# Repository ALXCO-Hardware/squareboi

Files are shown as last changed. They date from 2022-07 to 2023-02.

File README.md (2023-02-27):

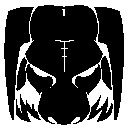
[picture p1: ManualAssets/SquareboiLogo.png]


# Squareboi

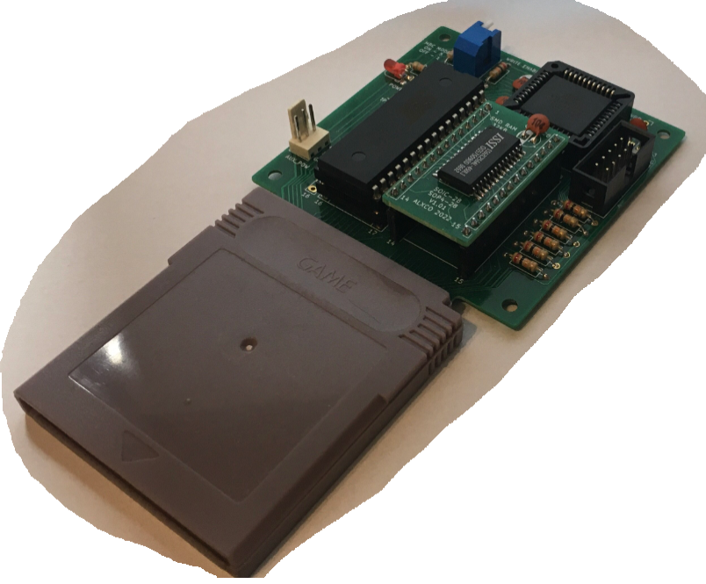
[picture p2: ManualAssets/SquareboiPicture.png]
Squareboi


Squareboi is an open hardware cartridge system for the Game Boy Color, made to be as accessible and DIY-friendly as possible.
Using a handful of off-the-shelf components, it provides the same functionality as an original cartridge, compatible with the majority of programs.
Additionally, an Arduino-based programmer allows for easy transfer of games and save data.

## Features

Up to 4MB ROM/32KB RAM storage space

Stores save data without needing a battery

Made of common, off-the-shelf parts

Fully compatible with MBC1 and MBC5 mappers, partial support for MBC2 and MBC3

Programmer works as a general purpose cartridge reader

Easy to build: A basic version can be made with entirely through-hole components

Powered by a single 5V rail

Compatible with third-party programmers, like the widespread GBxCart RW

## Manual

A thorough explanation of how the system works, and how to assemble it, can be found in the manual file, [HERE.](/Manual.pdf)

## Acknowledgements

Squareboi's existence is only possible due to the continued efforts of multiple individuals dedicated to reverse engineering and documenting the Game Boy hardware.
A full list of those whose work I've built upon can be found within the manual.

Still, I'd like to say it again: Thanks to all of you! I wouldn't have gotten here alone.

## Links

[Official video assembly guide](https://www.youtube.com/playlist?list=PL5rO9JlAGJ3c4BWqF0iWA5yTH4LZhnxgb)

[Squareboi featured on Hackaday](https://hackaday.com/2022/08/16/squareboi-is-the-diy-game-boy-cart-youve-always-wanted/)

## License

Squareboi is the work of a hobbyist – And while significant care was 
taken to make it reliable, I cannot guarantee that it will work in 
your specific use case, or that it will be compatible with your 
hardware.

Squareboi is licensed under the Creative Commons Attribution 4.0 
International License (CC BY 4.0). 
https://creativecommons.org/licenses/by/4.0/#deed-conditions

In essence, if you share or adapt this work, you must credit the 
author (ALXCO), and provide a link to the Squareboi repository, at:
https://github.com/ALXCO-Hardware/squareboi

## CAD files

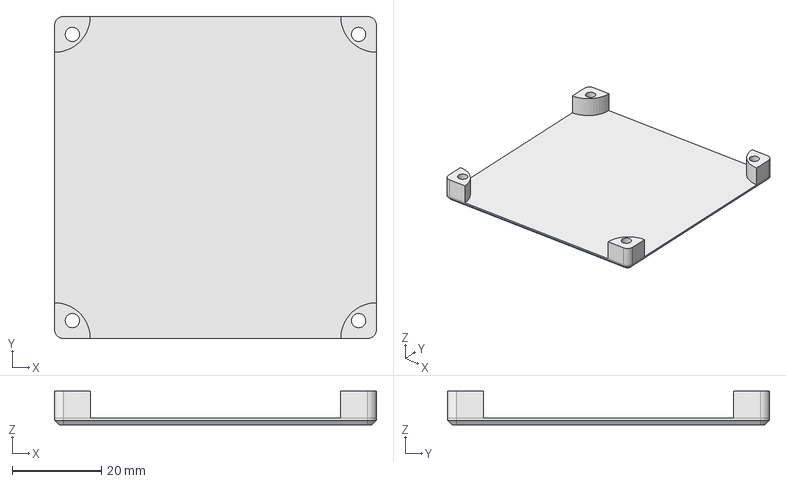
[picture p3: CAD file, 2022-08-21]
Case/Source/Backplate.FCStd
72.0 x 72.0 x 7.50 mm

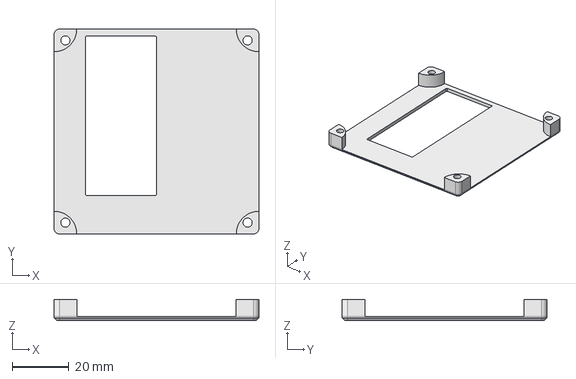
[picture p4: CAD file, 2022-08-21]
Case/Source/Backplate_Stack.FCStd
72.0 x 72.0 x 7.50 mm

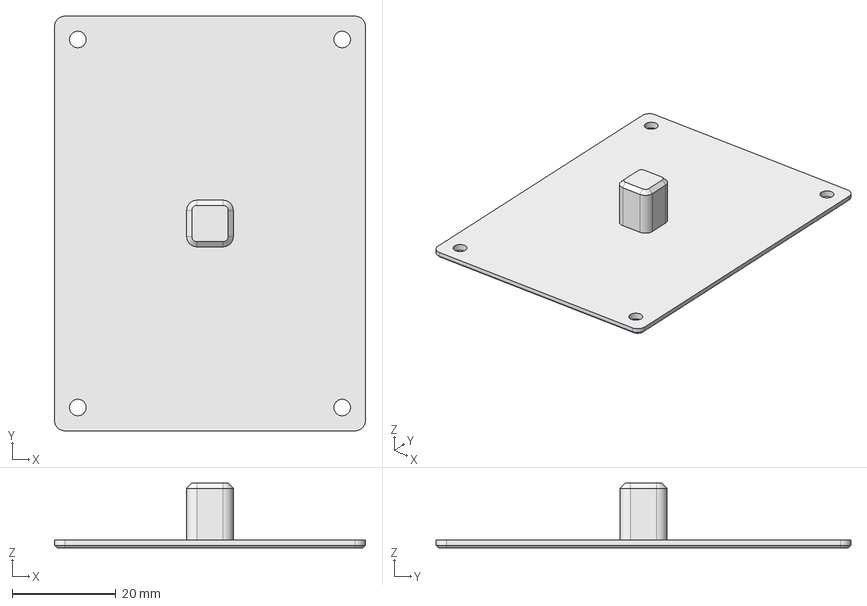
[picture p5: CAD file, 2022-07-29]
Case/Source/Devboard_Backplate.FCStd
60.0 x 80.0 x 12.5 mm

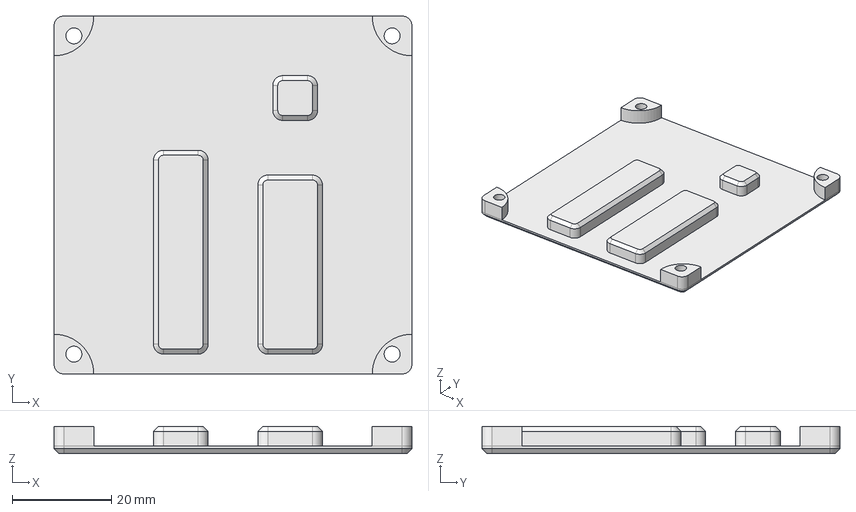
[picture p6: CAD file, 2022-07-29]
Case/Source/Backplate_Supports.FCStd
72.0 x 72.0 x 5.50 mm

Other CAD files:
Case/Backplate.amf
Case/Backplate_Stack.amf
Case/Backplate_Supports.amf
Case/Devboard_Backplate.amf

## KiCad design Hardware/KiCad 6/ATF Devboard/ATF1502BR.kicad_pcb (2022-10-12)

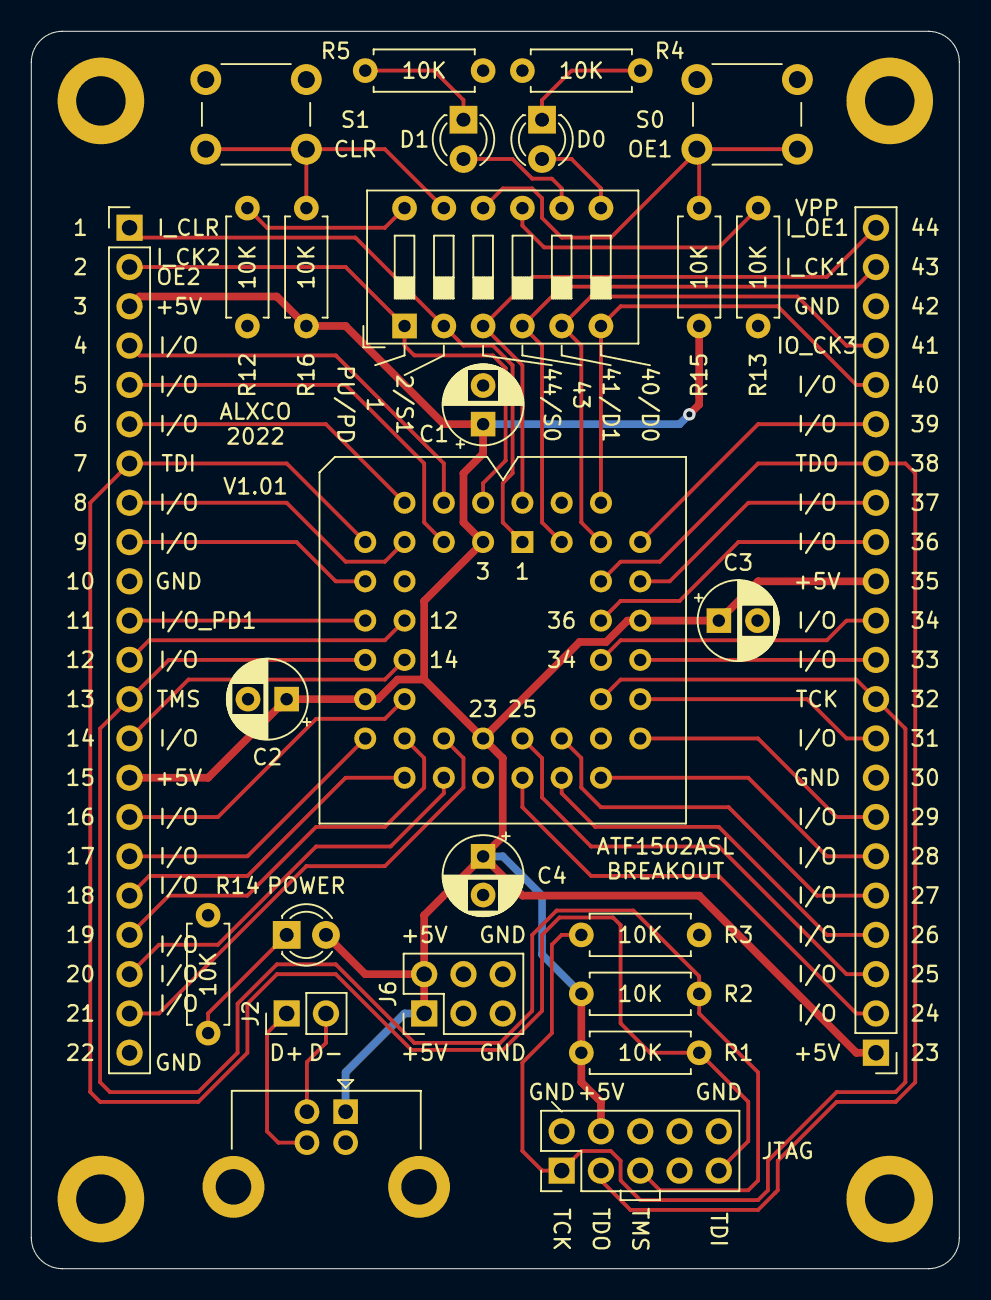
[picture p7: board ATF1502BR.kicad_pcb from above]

Board: 2 copper layers, 60.0 x 80.0 mm, 27 parts (0 on the bottom side), 49 nets.

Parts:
C1, C2, C3, C4: 220nF; CP_Radial_D5.0mm_P2.50mm
D0, D1, D8: LED; LED_D3.0mm
J1: USB_B; USB_B_Lumberg_2411_02_Horizontal
J2: Conn_01x02; PinHeader_1x02_P2.54mm_Vertical
J3, J5: Conn_01x22; PinHeader_1x22_P2.54mm_Vertical
J4: Conn_02x05_Odd_Even; PinHeader_2x05_P2.54mm_Vertical
J6: Conn_02x05_Odd_Even; PinHeader_2x03_P2.54mm_Vertical
R1, R2, R3, R4, R5, R12, R13, R14, R15, R16: 10K; R_Axial_DIN0207_L6.3mm_D2.5mm_P7.62mm_Horizontal
SW1: SW_DIP_x06; SW_DIP_SPSTx06_Slide_9.78x17.42mm_W7.62mm_P2.54mm
SW4, SW5: SW_Push; SW_PUSH_6mm_H5mm
U1: ATF1502-PLCC; PLCC-44_THT-Socket

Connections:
+5V: C1.1, C2.1, C3.1, C4.1, D8.2, J1.1, J3.3, J3.15, J4.4, J5.1, J5.13, J6.1, J6.2, R1.1, R2.1, R15.1, R16.1, U1.3, U1.15, U1.23, U1.35
/IO_4: J3.4, U1.4
/IO_5: J3.5, U1.5
/IO_6: J3.6, U1.6
/IO_8: J3.8, U1.8
/IO_9: J3.9, U1.9
/IO_12: J3.12, U1.12
/IO_14: J3.14, U1.14
/IO_16: J3.16, U1.16
/IO_17: J3.17, U1.17
/IO_18: J3.18, U1.18
/IO_19: J3.19, U1.19
/IO_20: J3.20, U1.20
/IO_21: J3.21, U1.21
/IO_24: J5.2, U1.24
/IO_26: J5.4, U1.26
/IO_27: J5.5, U1.27
/IO_28: J5.6, U1.28
/IO_29: J5.7, U1.29
/IO_31: J5.9, U1.31
/IO_33: J5.11, U1.33
/IO_34: J5.12, U1.34
/IO_36: J5.14, U1.36
/IO_37: J5.15, U1.37
/IO_39: J5.17, U1.39
/IO_40: J5.18, SW1.6, U1.40
/IO_GCLK3: J5.19, SW1.5, U1.41
/IO_PD1: J3.11, U1.11
/IO_PD2: J5.3, U1.25
/I_GCLK1: J5.21, SW1.4, U1.43
/I_GCLK2_OE2: J3.2, SW1.1, U1.2
/I_GCLR: J3.1, SW1.2, U1.1
/I_OE1: J5.22, SW1.3, U1.44
/LED0: D0.2, SW1.7
/LED1: D1.2, SW1.8
/SW_GCLR: R16.2, SW1.11, SW5.1
/SW_OE1: R15.2, SW1.10, SW4.1
/TCK: J4.1, J5.10, R3.2, U1.32
/TDI: J3.7, J4.9, R1.2, U1.7
/TDO: J4.3, J5.16, U1.38
/TMS: J3.13, J4.5, R2.2, U1.13
/USBN: J1.2, J2.2
/USBP: J1.3, J2.1
GND: C1.2, C2.2, C3.2, C4.2, J1.4, J1.5, J3.10, J3.22, J4.2, J4.10, J5.8, J5.20, J6.5, J6.6, R3.1, R4.2, R5.2, R12.2, R13.2, R14.2, SW4.2, SW5.2, U1.10, U1.22, U1.30, U1.42
unnamed: D0.1, R4.1
unnamed: D1.1, R5.1
unnamed: D8.1, R14.1
unnamed: R12.1, SW1.12
unnamed: R13.1, SW1.9

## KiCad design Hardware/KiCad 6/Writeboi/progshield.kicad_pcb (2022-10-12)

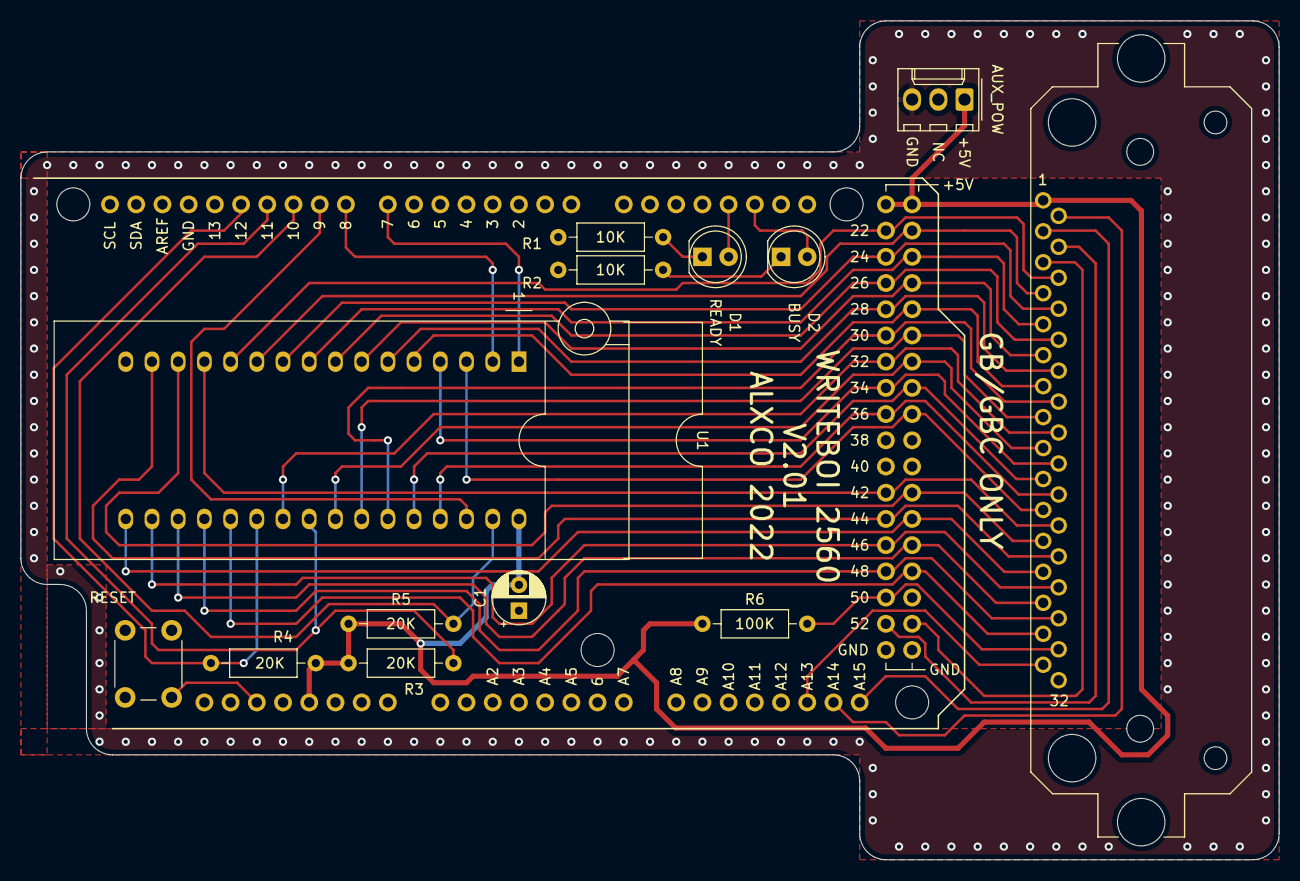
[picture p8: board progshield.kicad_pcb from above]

Board: 2 copper layers, 121.9 x 81.3 mm, 14 parts (0 on the bottom side), 43 nets.

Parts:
C1: 100n; CP_Radial_D5.0mm_P2.50mm
D1, D2: LED; LED_D5.0mm
J1: GB-CART; GameBoy_Cartridge_DMG_1x32_P1.50mm_Socket_Horizontal
J2: AUX_POW; Molex_KK-254_AE-6410-03A_1x03_P2.54mm_Vertical
R1, R2: 10K; R_Axial_DIN0207_L6.3mm_D2.5mm_P10.16mm_Horizontal
R3, R4, R5: 20K; R_Axial_DIN0207_L6.3mm_D2.5mm_P10.16mm_Horizontal
R6: 100K; R_Axial_DIN0207_L6.3mm_D2.5mm_P10.16mm_Horizontal
SW1: SW_Push; SW_PUSH_6mm_H5mm
U1: SST39SF040; DIP_Socket-32_W11.9_W12.7_W15.24_W17.78_W18.5_3M_232-1285-0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
XA1: Arduino_Mega2560_Shield

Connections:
+5V: C1.2, J1.1, J2.1, R3.1, R4.1, R5.1, R6.1, U1.32, XA1.5V1, XA1.5V3, XA1.5V4
/A0: J1.6, U1.12, XA1.D22
/A1: J1.7, U1.11, XA1.D23
/A2: J1.8, U1.10, XA1.D24
/A3: J1.9, U1.9, XA1.D25
/A4: J1.10, U1.8, XA1.D26
/A5: J1.11, U1.7, XA1.D27
/A6: J1.12, U1.6, XA1.D28
/A7: J1.13, U1.5, XA1.D29
/A8: J1.14, U1.27, XA1.D30
/A9: J1.15, U1.26, XA1.D31
/A10: J1.16, U1.23, XA1.D32
/A11: J1.17, U1.25, XA1.D33
/A12: J1.18, U1.4, XA1.D34
/A13: J1.19, U1.28, XA1.D35
/A14: J1.20, U1.29, XA1.D36
/A15: J1.21, U1.3, XA1.D37
/A16: U1.2, XA1.D8
/A17: U1.30, XA1.D9
/A18: U1.1, XA1.D7
/CLK: J1.2, XA1.A14
/CRT_CS_N: J1.5, XA1.D53
/CRT_PG_N: J1.31, XA1.A13
/CRT_RD_N: J1.4, XA1.D52
/CRT_WR_N: J1.3, XA1.A15
/D0: J1.22, U1.13, XA1.D42
/D1: J1.23, U1.14, XA1.D43
/D2: J1.24, U1.15, XA1.D44
/D3: J1.25, U1.17, XA1.D45
/D4: J1.26, U1.18, XA1.D46
/D5: J1.27, U1.19, XA1.D47
/D6: J1.28, U1.20, XA1.D48
/D7: J1.29, U1.21, XA1.D49
/DIP_CE_N: R4.2, U1.22, XA1.D12
/DIP_OE_N: R3.2, U1.24, XA1.D11
/DIP_WE_N: R5.2, U1.31, XA1.D10
/LED_BY: D2.2, XA1.D19
/LED_RY: D1.2, XA1.D18
/RST_N: J1.30, R6.2, XA1.D50
GND: C1.1, J1.32, J2.3, R1.2, R2.2, SW1.2, U1.16, XA1.GND1, XA1.GND2, XA1.GND3, XA1.GND5, XA1.GND6
unnamed: D1.1, R1.1
unnamed: D2.1, R2.1
unnamed: SW1.1, XA1.RST1

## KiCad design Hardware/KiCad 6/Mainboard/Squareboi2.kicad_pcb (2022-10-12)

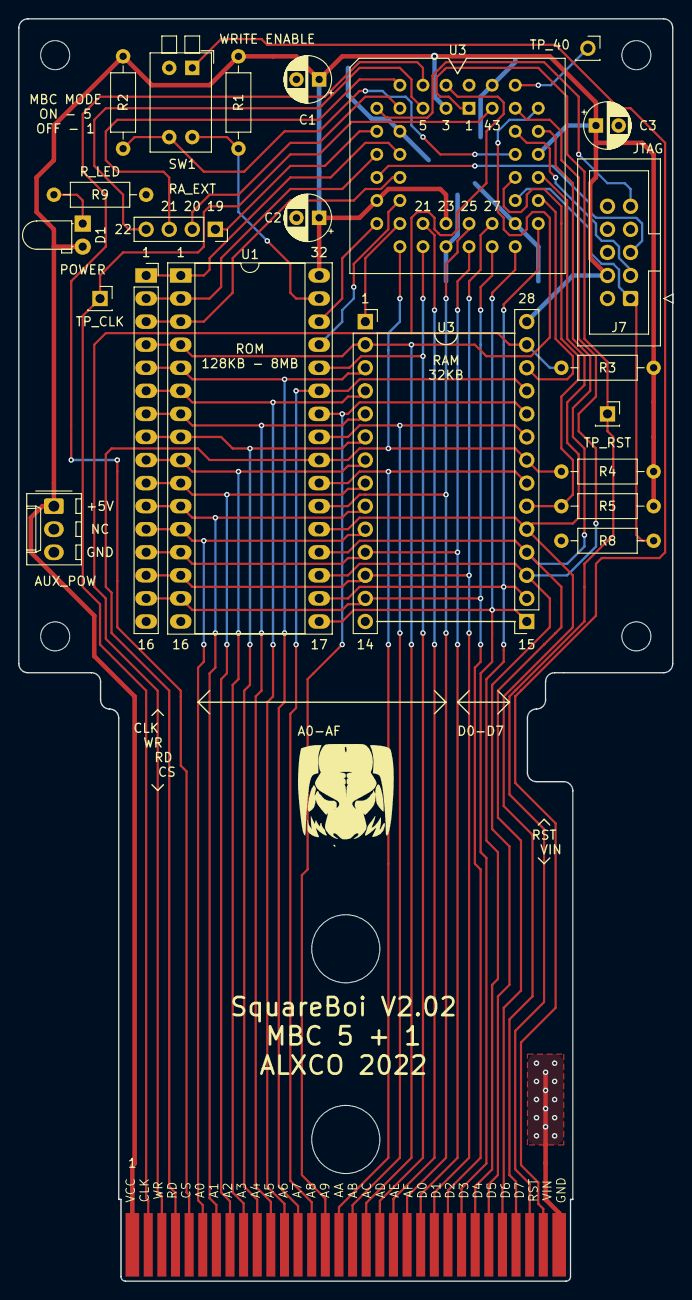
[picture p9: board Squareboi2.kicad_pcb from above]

Board: 2 copper layers, 72.0 x 139.0 mm, 24 parts (0 on the bottom side), 52 nets.

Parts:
C1, C2, C3: 100n; CP_Radial_D5.0mm_P2.50mm
D1: LED; LED_D3.0mm_Horizontal_O1.27mm_Z2.0mm
J1: GB-CART; GB_CART_FINGERS
J2: ROMC_L; PinSocket_1x16_P2.54mm_Vertical
J4: ROMC_C; PinSocket_1x04_P2.54mm_Vertical
J5: RAMC_L; PinSocket_1x14_P2.54mm_Vertical
J6: RAMC_R; PinSocket_1x14_P2.54mm_Vertical
J7: JTAG; IDC-Header_2x05_P2.54mm_Vertical
J8: AUX_POW; Molex_KK-254_AE-6410-03A_1x03_P2.54mm_Vertical
J10: TP_CLK; PinSocket_1x01_P2.54mm_Vertical
J11: TP_40; PinSocket_1x01_P2.54mm_Vertical
J12: TP_RST; PinSocket_1x01_P2.54mm_Vertical
R1, R2, R3, R4, R5, R8, R9: 20K; R_Axial_DIN0207_L6.3mm_D2.5mm_P10.16mm_Horizontal
SW1: SW_DIP_x02; SW_DIP_SPSTx02_Piano_10.8x6.64mm_W7.62mm_P2.54mm
U1: SST39SF040; DIP-32_W15.24mm_Socket_LongPads
U3: ATF1502AS-PLCC; PLCC-44_THT-Socket

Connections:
+5V: C1.1, C2.1, C3.1, D1.2, J1.1, J6.14, J7.4, J8.1, R1.1, R2.2, R3.1, R4.1, R5.1, U1.32, U3.3, U3.15, U3.23, U3.35
/A0: J1.6, J2.12, J5.10, U1.12
/A1: J1.7, J2.11, J5.9, U1.11
/A2: J1.8, J2.10, J5.8, U1.10
/A3: J1.9, J2.9, J5.7, U1.9
/A4: J1.10, J2.8, J5.6, U1.8
/A5: J1.11, J2.7, J5.5, U1.7
/A6: J1.12, J2.6, J5.4, U1.6
/A7: J1.13, J2.5, J5.3, U1.5
/A8: J1.14, J6.11, U1.27
/A9: J1.15, J6.10, U1.26
/A10: J1.16, J6.7, U1.23
/A11: J1.17, J6.9, U1.25
/A12: J1.18, J2.4, J5.2, U1.4, U3.39
/A13: J1.19, U1.28, U3.20
/A14: J1.20, U3.21
/A15: J1.21, U1.22, U3.25
/AA13: J6.12, U3.31
/AA14: J5.1, U3.19
/CS_N: J1.5, U3.4
/D0: J1.22, J2.13, J5.11, U1.13, U3.24
/D1: J1.23, J2.14, J5.12, U1.14, U3.27
/D2: J1.24, J2.15, J5.13, U1.15, U3.26
/D3: J1.25, J6.1, U1.17, U3.28
/D4: J1.26, J6.2, U1.18, U3.29
/D5: J1.27, J6.3, U1.19, U3.41
/D6: J1.28, J6.4, U1.20, U3.37
/D7: J1.29, J6.5, U1.21, U3.33
/GBCLK: J1.2, J10.1, U3.43
/IO40: J11.1, U3.40
/MODE: R2.1, SW1.3, U3.36
/RA14: U1.29, U3.16
/RA15: J2.3, U1.3, U3.14
/RA16: J2.2, U1.2, U3.11
/RA17: U1.30, U3.17
/RA18: J2.1, U1.1, U3.12
/RA19: J4.1, U3.9
/RA20: J4.2, U3.8
/RA21: J4.3, U3.6
/RA22: J4.4, U3.5
/RAMCS_N: J6.6, R5.2, U3.34
/RD_N: J1.4, J6.8, R4.2, U1.24, U3.18
/ROMWR_N: R1.2, SW1.4, U1.31
/RS_N: J1.30, J12.1, U3.1
/TCK: J7.1, R8.1, U3.32
/TDI: J7.9, U3.7
/TDO: J7.3, U3.38
/TMS: J7.5, U3.13
/VIN: J1.31, SW1.1
/WR_N: J1.3, J6.13, R3.2, U3.2
GND: C1.2, C2.2, C3.2, J1.32, J2.16, J5.14, J7.2, J7.10, J8.3, R8.2, R9.2, SW1.2, U1.16, U3.10, U3.22, U3.30, U3.42, U3.44
unnamed: D1.1, R9.1

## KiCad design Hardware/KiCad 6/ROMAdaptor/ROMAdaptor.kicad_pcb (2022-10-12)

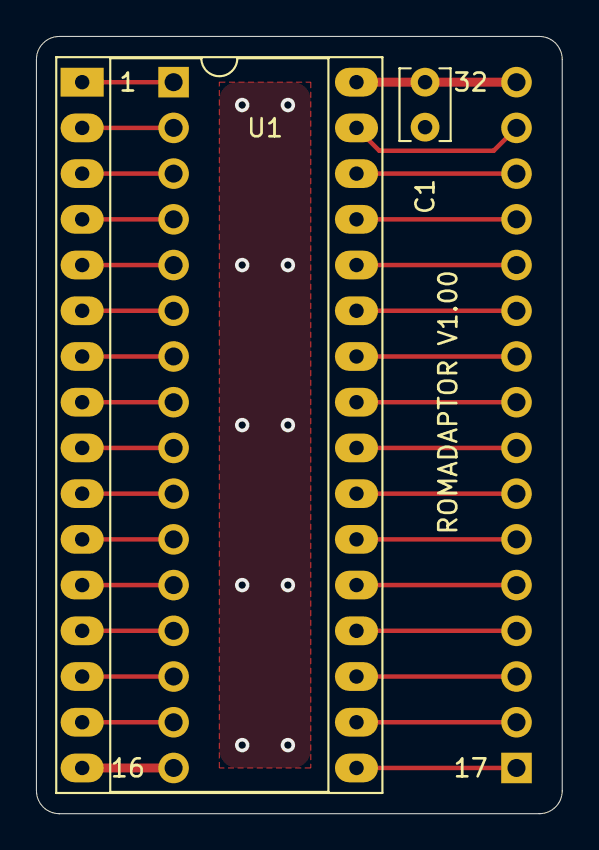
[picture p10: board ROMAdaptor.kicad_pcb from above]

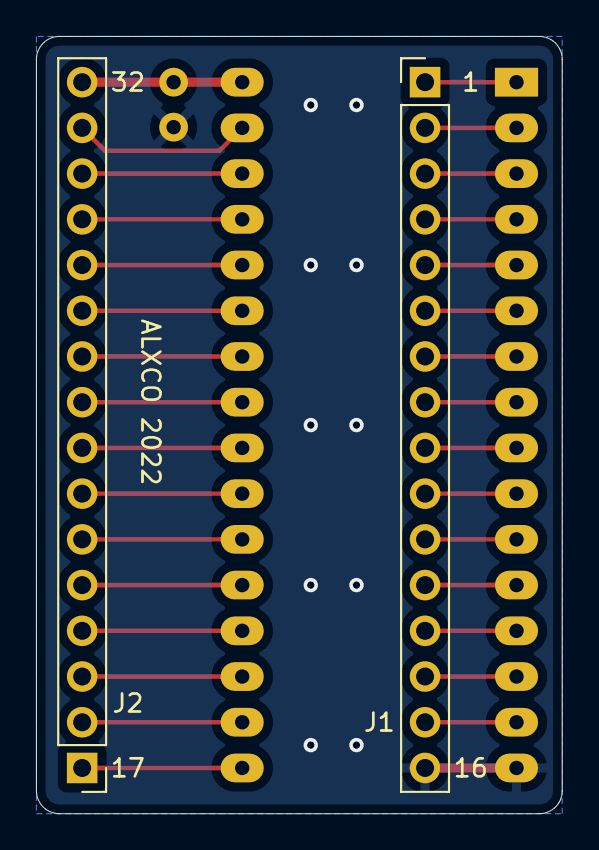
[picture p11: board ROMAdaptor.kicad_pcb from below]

Board: 2 copper layers, 29.2 x 43.2 mm, 4 parts (2 on the bottom side), 32 nets.

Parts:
C1: 100n; C_Disc_D3.8mm_W2.6mm_P2.50mm
J1, J2: Conn_01x16; PinHeader_1x16_P2.54mm_Vertical
U1: SST39SF040; DIP-32_W15.24mm_Socket_LongPads

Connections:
+5V: C1.1, J2.16, U1.32
/A0: J1.12, U1.12
/A1: J1.11, U1.11
/A2: J1.10, U1.10
/A3: J1.9, U1.9
/A4: J1.8, U1.8
/A5: J1.7, U1.7
/A6: J1.6, U1.6
/A7: J1.5, U1.5
/A8: J2.11, U1.27
/A9: J2.10, U1.26
/A10: J2.7, U1.23
/A11: J2.9, U1.25
/A12: J1.4, U1.4
/A13: J2.12, U1.28
/A14: J2.13, U1.29
/A15: J1.3, U1.3
/A16: J1.2, U1.2
/A17: J2.14, U1.30
/A18: J1.1, U1.1
/D0: J1.13, U1.13
/D1: J1.14, U1.14
/D2: J1.15, U1.15
/D3: J2.1, U1.17
/D4: J2.2, U1.18
/D5: J2.3, U1.19
/D6: J2.4, U1.20
/D7: J2.5, U1.21
/RD_N: J2.8, U1.24
/ROMCS_N: J2.6, U1.22
/WR_N: J2.15, U1.31
GND: C1.2, J1.16, U1.16

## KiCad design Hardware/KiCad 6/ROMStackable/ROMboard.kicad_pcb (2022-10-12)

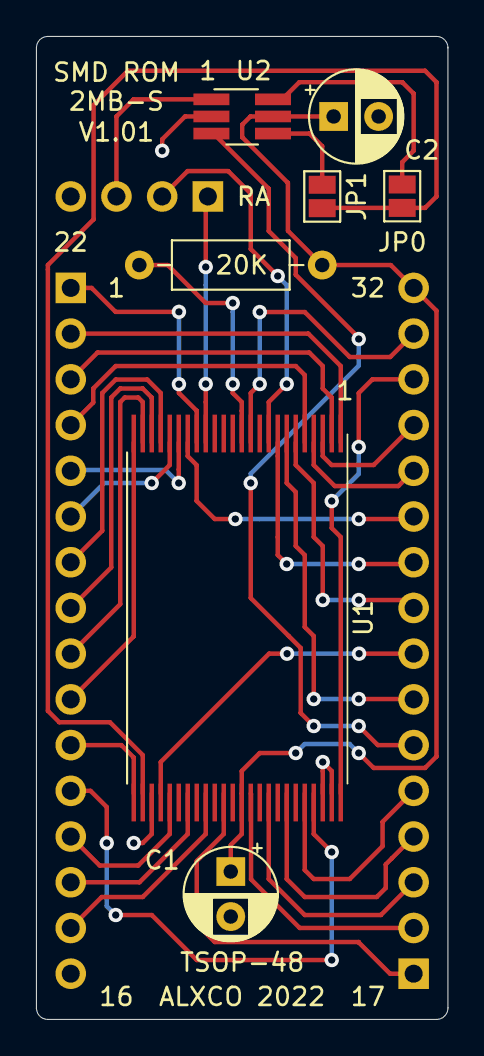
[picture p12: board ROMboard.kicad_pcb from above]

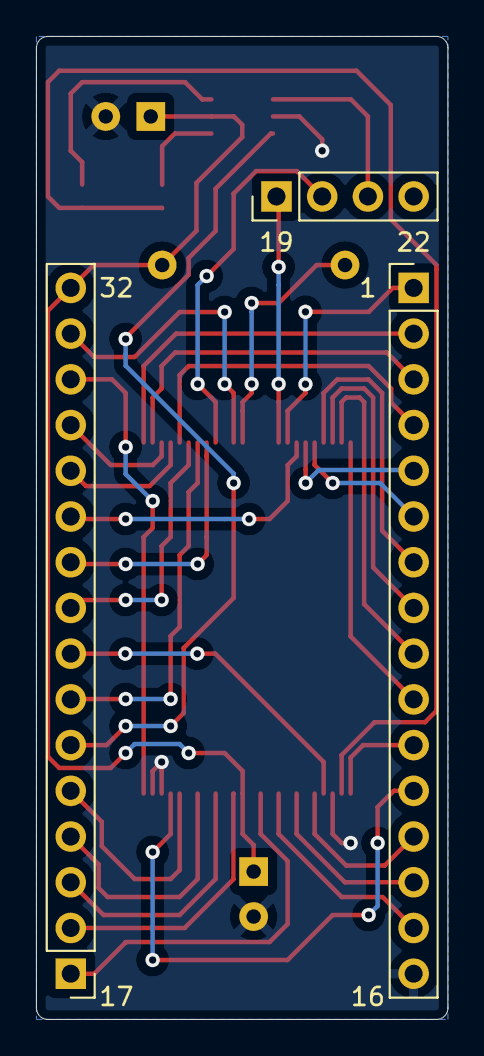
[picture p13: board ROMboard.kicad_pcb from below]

Board: 2 copper layers, 22.9 x 54.6 mm, 10 parts (3 on the bottom side), 39 nets.

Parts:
C1, C2: 100n; CP_Radial_D5.0mm_P2.50mm
J0, J1: Conn_01x16; PinHeader_1x16_P2.54mm_Vertical
J2: Conn_01x04; PinHeader_1x04_P2.54mm_Vertical
JP0, JP1: Jumper_2_Open; SolderJumper-2_P1.3mm_Open_Pad1.0x1.5mm
R1: 20K; R_Axial_DIN0207_L6.3mm_D2.5mm_P10.16mm_Horizontal
U1: M29F160; TSOP-I-48_18.4x12mm_P0.5mm
U2: 74LVC1G19; TSOT-23-6_HandSoldering

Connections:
+5V: C1.1, C2.1, J1.16, R1.1, U1.37, U2.5
/A0: J0.12, U1.45
/A1: J0.11, U1.25
/A2: J0.10, U1.24
/A3: J0.9, U1.23
/A4: J0.8, U1.22
/A5: J0.7, U1.21
/A6: J0.6, U1.20
/A7: J0.5, U1.19
/A8: J1.11, U1.18
/A9: J1.10, U1.8
/A10: J1.7, U1.7
/A11: J1.9, U1.6
/A12: J0.4, U1.5
/A13: J1.12, U1.4
/CE_N: J1.6, U2.3
/CE_OUT_N: JP0.2, JP1.2, U1.26
/D0: J0.13, U1.29
/D1: J0.14, U1.31
/D2: J0.15, U1.33
/D3: J1.1, U1.35
/D4: J1.2, U1.38
/D5: J1.3, U1.40
/D6: J1.4, U1.42
/D7: J1.5, U1.44
/RA14: J1.13, U1.3
/RA15: J0.3, U1.2
/RA16: J0.2, U1.1
/RA17: J1.14, U1.48
/RA18: J0.1, U1.17
/RA19: J2.1, U1.16
/RA20: J2.2, U1.9
/RA21: J2.3, U2.1
/RD_N: J1.8, U1.28
/ROMWR_N: J1.15, U1.11
/RST_N: R1.2, U1.12
GND: C1.2, C2.2, J0.16, U1.27, U1.46, U1.47, U2.2
unnamed: JP0.1, U2.6
unnamed: JP1.1, U2.4

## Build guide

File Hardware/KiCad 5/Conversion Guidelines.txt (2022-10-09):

Converting a project to KiCad 6:

Base:
1- Open project with KiCad 6 
2- Open schematic editor, save.
3- Open PCB editor, save.
4- Open Preferences, Manage Symbol Libraries, migrate all project-specific libraries
5- Open Preferences, Manage Footprint Libraries, migrate all project-specific libraries

3D viewer fix:
6- open .kicad_pcb file in a text editor, replace all instances of KISYS3DMOD with KICAD6_3DMODEL_DIR

Cleanup:
7- Delete:
-backup folder
-[project].pro
-[project].sch
-[project].sch-bak
-[project]-cache.lib
-[project].dcm (if exists)
-.lib files for project libraries

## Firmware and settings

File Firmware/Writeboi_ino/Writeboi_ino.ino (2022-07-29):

//Writeboi firmware
//V1.00
//For use with Writeboi board V2.01

//ALXCO 2022


//Global build ID:
byte GLB_buildID = 0x01;


//PINOUTS!

#define GB_A0 22
#define GB_A1 23
#define GB_A2 24
#define GB_A3 25
#define GB_A4 26
#define GB_A5 27
#define GB_A6 28
#define GB_A7 29
#define GB_A8 30
#define GB_A9 31
#define GB_A10 32
#define GB_A11 33
#define GB_A12 34
#define GB_A13 35
#define GB_A14 36
#define GB_A15 37

#define DIP_A16 8
#define DIP_A17 9
#define DIP_A18 7

#define GB_D0 42
#define GB_D1 43
#define GB_D2 44
#define GB_D3 45
#define GB_D4 46
#define GB_D5 47
#define GB_D6 48
#define GB_D7 49

#define DIP_CE_N 12
#define DIP_OE_N 11
#define DIP_WE_N 10

#define CRT_CS_N 53
#define CRT_RD_N 52
#define CRT_WR_N A15
#define CRT_PG_N A13
#define CRT_RST_N 50
#define CRT_CLK A14

#define LED_BY 19
#define LED_RY 18

//Compile-time definitions!

#define ARRSIZE 1024

//Globals!
unsigned long GLB_MBCROMBank = 0;
bool GLB_MBCROMBankValid = false;
unsigned long GLB_MBCRAMBank = 0;
bool GLB_MBCRAMBankValid = false;



byte GLB_bytearray[ARRSIZE] = {};

//Lookup table for inverting a byte
//Use with the following code to reverse a variable X:
//X = (GLB_reverselookup[ X & 0b1111] << 4) | GLB_reverselookup[X>>4];
byte GLB_reverselookup[16] = {
0x0, 0x8, 0x4, 0xc, 0x2, 0xa, 0x6, 0xe,
0x1, 0x9, 0x5, 0xd, 0x3, 0xb, 0x7, 0xf, };


//Port manip pin-setting macros!


//CRT_CS_N:PIN53:PB0
#define PM_CRT_CS_N_HIGH() PORTB=PORTB|0b00000001
#define PM_CRT_CS_N_LOW()  PORTB=PORTB&0b11111110

//CRT_RD_N:PIN52:PB1

#define PM_CRT_RD_N_HIGH() PORTB=PORTB|0b00000010
#define PM_CRT_RD_N_LOW()  PORTB=PORTB&0b11111101

//CRT_WR_N:PINA15:PK7
#define PM_CRT_WR_N_HIGH() PORTK=PORTK|0b10000000
#define PM_CRT_WR_N_LOW()  PORTK=PORTK&0b01111111


//CRT_PG_N:PINA13:PK5
#define PM_CRT_PG_N_HIGH() PORTK=PORTK|0b00100000
#define PM_CRT_PG_N_LOW()  PORTK=PORTK&0b11011111



//DIP_CE_N:PIN12:PB6
#define PM_DIP_CE_N_HIGH() PORTB=PORTB|0b01000000
#define PM_DIP_CE_N_LOW()  PORTB=PORTB&0b10111111

//DIP_OE_N:PIN11:PB5
#define PM_DIP_OE_N_HIGH() PORTB=PORTB|0b00100000
#define PM_DIP_OE_N_LOW()  PORTB=PORTB&0b11011111

//DIP_WE_N:PIN10:PB4
#define PM_DIP_WE_N_HIGH() PORTB=PORTB|0b00010000
#define PM_DIP_WE_N_LOW()  PORTB=PORTB&0b11101111





void setup() {
  // Set all control lines to an inactive state
  digitalWrite(DIP_CE_N, HIGH);
  digitalWrite(DIP_OE_N, HIGH);
  digitalWrite(DIP_WE_N, HIGH);
  pinMode(DIP_CE_N, OUTPUT);
  pinMode(DIP_OE_N, OUTPUT);
  pinMode(DIP_WE_N, OUTPUT);

  digitalWrite(CRT_CS_N, HIGH);
  digitalWrite(CRT_RD_N, HIGH);
  digitalWrite(CRT_WR_N, HIGH);
  digitalWrite(CRT_PG_N, HIGH);
  digitalWrite(CRT_CLK, LOW);

  pinMode(CRT_CS_N, OUTPUT);
  pinMode(CRT_RD_N, OUTPUT);
  pinMode(CRT_WR_N, OUTPUT);
  pinMode(CRT_PG_N, OUTPUT);
  pinMode(CRT_CLK, OUTPUT);

  setDataPinMode(INPUT);


  pinMode(GB_A0, OUTPUT);
  pinMode(GB_A1, OUTPUT);
  pinMode(GB_A2, OUTPUT);
  pinMode(GB_A3, OUTPUT);
  pinMode(GB_A4, OUTPUT);
  pinMode(GB_A5, OUTPUT);
  pinMode(GB_A6, OUTPUT);
  pinMode(GB_A7, OUTPUT);
  pinMode(GB_A8, OUTPUT);
  pinMode(GB_A9, OUTPUT);
  pinMode(GB_A10, OUTPUT);
  pinMode(GB_A11, OUTPUT);
  pinMode(GB_A12, OUTPUT);
  pinMode(GB_A13, OUTPUT);
  pinMode(GB_A14, OUTPUT);
  pinMode(GB_A15, OUTPUT);
  
  pinMode(DIP_A16, OUTPUT);
  pinMode(DIP_A17, OUTPUT);
  pinMode(DIP_A18, OUTPUT);

  //LED test, reset cartridge
  digitalWrite(LED_RY, HIGH);
  digitalWrite(LED_BY, HIGH);
  pinMode(LED_BY, OUTPUT);
  pinMode(LED_RY, OUTPUT);
  digitalWrite(CRT_RST_N, LOW);
  pinMode(CRT_RST_N, OUTPUT);


  delay(1500);

  digitalWrite(LED_RY, LOW);
  digitalWrite(LED_BY, LOW);
  pinMode(CRT_RST_N, INPUT);

  initializeByteArray();
  
  delay(50);

  GLB_MBCROMBank = 0;
  GLB_MBCRAMBank = 0;
  GLB_MBCROMBankValid = false;
  GLB_MBCRAMBankValid = false;  

  delay(500);


  
  Serial.begin(115200);
  setBusy(false);





}

void loop() {
  // put your main code here, to run repeatedly:
  serialManager();
}

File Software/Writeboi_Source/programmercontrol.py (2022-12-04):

import serial
import binascii
import time
import timeit
import cProfile

class programmerException(Exception):
    pass;


def getBuildID(manager,targetdevice):
    try:     
        command = "0,0,0\n";
        targetdevice.write(command.encode('utf-8'));
        response = int((targetdevice.readline()).decode('utf-8').rstrip(),base=16);
        return response;
    except serial.SerialException:
        manager.logprint("Programmer access denied.", text_color = "red");
        raise programmerException("");

def dumpHeader(manager,targetdevice,interface):
    if interface == "MBC":
        commandID = "4,";
    elif interface == "DIP":
        commandID = "70,";
    else:
        manager.logprint("Invalid interface selected: " + str(interface), text_color = "red");
        raise programmerException("");
    try:     
        command = commandID+"0,0\n";
        targetdevice.write(command.encode('utf-8'));
        response = targetdevice.read(1024);
        targetdevice.readline();
        return response[:];
    except serial.SerialException:
        manager.logprint("Programmer access denied.", text_color = "red");
        raise programmerException("");



def chipErase(manager,targetdevice,interface,targetIC):
    address = "0";
    
    if interface == "MBC1":
        if targetIC == "SST":
            commandID = "39,";
        elif targetIC == "M29":
            commandID = "59,";
        else:
            manager.logprint("Invalid IC selected: " + str(targetIC), text_color = "red");
            raise programmerException("");
        
    elif interface == "MBC5":
        if targetIC == "SST":
            commandID = "49,";
        elif targetIC == "M29":
            commandID = "69,";
        elif targetIC == "M29Chip2":
            commandID = "69,";
            address = "2097152";
        else:
            manager.logprint("Invalid IC selected: " + str(targetIC), text_color = "red");
            raise programmerException("");
        
    elif interface == "DIP":
        if targetIC == "SST":
            commandID = "19,";
        else:
            manager.logprint("Invalid IC selected: " + str(targetIC), text_color = "red");
            raise programmerException("");         
        
    else:
        manager.logprint("Invalid IC selected: " + str(targetIC), text_color = "red");
        raise programmerException("");

    if targetIC == "M29Chip2":
        manager.logprint("Starting Erase: Chip 2");
    else:
        manager.logprint("Starting Erase.");
    command = commandID+address+",0\n";
    targetdevice.write(command.encode('utf-8'));

    
    try:
        while True:
            response = int((targetdevice.readline()).decode('utf-8').rstrip(),base=16);
            if response == 0:
                manager.logprint("Erase successful.");
                return 0;
            elif response == 2:
                manager.logprint(".",end="");
                manager.update(timeout=1);
                
            else:
                manager.logprint("Erase error.", text_color = "red");
                raise programmerException("");
    except serial.SerialException:
        manager.logprint("Programmer access denied.", text_color = "red");
        raise programmerException("");





def chunkRead(manager,targetdevice,numkb,interface,targetIC,startkb=0):

    if interface == "MBC1":
        if targetIC == "RAM": commandID = "81,";
        elif targetIC == "ROM": commandID = "80,";
        else:
            manager.logprint("Invalid IC selected.", text_color = "red");
            raise programmerException("");
        
    elif interface == "MBC5":
        if targetIC == "RAM": commandID = "91,";
        elif targetIC == "ROM": commandID = "90,";
        else:
            manager.logprint("Invalid IC selected.", text_color = "red");
            raise programmerException("");
        
    elif interface == "DIP": 
        if targetIC == "ROM": commandID = "70,";
        else:
            manager.logprint("Invalid IC selected.", text_color = "red");
            raise programmerException("");
        
    else:
        manager.logprint("Invalid interface selected: " + str(interface), text_color = "red");
        raise programmerException("");
    
    manager.logprint("Starting Chunkread.")
    manager.progbar.update(current_count=0, max=numkb);
    t0 = time.time();
    curpos = startkb;
    chunklist = [];

    try:
        while curpos<startkb+numkb:
            if manager.stoprequested:
                manager.logprint("Read interrupted by user.");
                manager.stoprequested = False;
                raise programmerException("");
            command = commandID+str(curpos*1024)+",0\n";
            targetdevice.write(command.encode('utf-8'));
            response = targetdevice.read(1024);
            chunklist.append(response);
            manager.progbar.update(current_count=curpos);
            curpos += 1;
            manager.update(timeout=1);
            targetdevice.readline();
    except serial.SerialException:
        manager.logprint("Programmer access denied.", text_color = "red");
        raise programmerException("");
    
    t1 = time.time();
    manager.logprint(str(numkb) + " kilobytes in " + str((t1-t0)) + " seconds.");
    manager.logprint("Read cycle complete.");
    return b"".join(chunklist);
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

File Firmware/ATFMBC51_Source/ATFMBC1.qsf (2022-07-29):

# -------------------------------------------------------------------------- #
#
# Copyright (C) 1991-2013 Altera Corporation
# Your use of Altera Corporation's design tools, logic functions 
# and other software and tools, and its AMPP partner logic 
# functions, and any output files from any of the foregoing 
# (including device programming or simulation files), and any 
# associated documentation or information are expressly subject 
# to the terms and conditions of the Altera Program License 
# Subscription Agreement, Altera MegaCore Function License 
# Agreement, or other applicable license agreement, including, 
# without limitation, that your use is for the sole purpose of 
# programming logic devices manufactured by Altera and sold by 
# Altera or its authorized distributors.  Please refer to the 
# applicable agreement for further details.
#
# -------------------------------------------------------------------------- #
#
# Quartus II 64-Bit
# Version 13.0.1 Build 232 06/12/2013 Service Pack 1 SJ Web Edition
# Date created = 21:20:45  December 04, 2021
#
# -------------------------------------------------------------------------- #
#
# Notes:
#
# 1) The default values for assignments are stored in the file:
#		ATFMBC1_assignment_defaults.qdf
#    If this file doesn't exist, see file:
#		assignment_defaults.qdf
#
# 2) Altera recommends that you do not modify this file. This
#    file is updated automatically by the Quartus II software
#    and any changes you make may be lost or overwritten.
#
# -------------------------------------------------------------------------- #


set_global_assignment -name FAMILY MAX7000S
set_global_assignment -name DEVICE "EPM7032SLC44-10"
set_global_assignment -name TOP_LEVEL_ENTITY ATFMBC1
set_global_assignment -name ORIGINAL_QUARTUS_VERSION "13.0 SP1"
set_global_assignment -name PROJECT_CREATION_TIME_DATE "21:20:45  DECEMBER 04, 2021"
set_global_assignment -name LAST_QUARTUS_VERSION "13.0 SP1"
set_global_assignment -name PROJECT_OUTPUT_DIRECTORY output_files
set_global_assignment -name ERROR_CHECK_FREQUENCY_DIVISOR "-1"
set_global_assignment -name MIN_CORE_JUNCTION_TEMP 0
set_global_assignment -name MAX_CORE_JUNCTION_TEMP 85
set_global_assignment -name VHDL_FILE ATFMBC1.vhd
set_global_assignment -name MAX7000_DEVICE_IO_STANDARD TTL
set_global_assignment -name USE_CONFIGURATION_DEVICE ON
set_location_assignment PIN_2 -to WR_N
set_location_assignment PIN_43 -to GBCLK
set_global_assignment -name SDC_FILE SDC1.sdc
set_location_assignment PIN_1 -to RESET_N
set_location_assignment PIN_20 -to A[13]
set_location_assignment PIN_21 -to A[14]
set_location_assignment PIN_25 -to A[15]
set_location_assignment PIN_19 -to AA[14]
set_location_assignment PIN_31 -to AA[13]
set_location_assignment PIN_4 -to CS_N
set_location_assignment PIN_29 -to D[4]
set_location_assignment PIN_28 -to D[3]
set_location_assignment PIN_26 -to D[2]
set_location_assignment PIN_27 -to D[1]
set_location_assignment PIN_24 -to D[0]
set_location_assignment PIN_12 -to RA[18]
set_location_assignment PIN_17 -to RA[17]
set_location_assignment PIN_11 -to RA[16]
set_location_assignment PIN_14 -to RA[15]
set_location_assignment PIN_16 -to RA[14]
set_location_assignment PIN_34 -to RAM_CS_N
set_location_assignment PIN_18 -to RD_N
set_location_assignment PIN_33 -to D[7]
set_location_assignment PIN_37 -to D[6]
set_location_assignment PIN_41 -to D[5]
set_location_assignment PIN_36 -to MBCMODE
set_location_assignment PIN_5 -to RA[22]
set_location_assignment PIN_6 -to RA[21]
set_location_assignment PIN_8 -to RA[20]
set_location_assignment PIN_9 -to RA[19]
set_location_assignment PIN_32 -to TCK
set_location_assignment PIN_7 -to TDI
set_location_assignment PIN_38 -to TDO
set_location_assignment PIN_13 -to TMS
set_location_assignment PIN_40 -to TP40
set_location_assignment PIN_44 -to TP44
set_location_assignment PIN_39 -to A[12]

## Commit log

2022-07-29 Initial upload
    [ATF1502BR-B_Cu.gbr, ATF1502BR-B_Mask.gbr, ATF1502BR-B_SilkS.gbr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]
2022-08-01 Fixed missing symbols in mainboard schematic
2022-08-01 Update Manual.pdf
    Added extra information regarding RAM chip selection and final assembly.
2022-08-04 SquareboiGUI updated
    Fixed Force Stop button not working. Re-compiled binaries.
2022-08-21 Increase backplate clearance
    Increase backplate and stacking backplate clearance from 4 to 6mm, to better fit SOIC-28 RAM.
    [Backplate.FCStd, Backplate.amf, Backplate_Stack.FCStd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]
2022-08-22 Refactor pullup resistors
    Add pullup to reset line for DMG compatibility, remove TDI and TMS pullups. Update mainboard to V2.02.
    [Squareboi2-B_CrtYd.gbr, Squareboi2-B_Cu.gbr, Squareboi2-B_Fab.gbr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]
2022-08-22 Update Manual.pdf
    Change resistor BOM, add new TDI/TMS pullup compile options for POF2JED.
2022-08-22 Update Manual.pdf
    Update current firmware version number to 2.02
2022-08-23 Update CPLD firmware to V203
    Recompiled to remove pin keeper option for DMG compatibility.
2022-08-23 Remove reset pullup from Mainboard
    Remove the RS_N pullup resistor after fixing pin keeper issue in software. Repackage corresponding gerbers.
    [Squareboi2-B_CrtYd.gbr, Squareboi2-B_Cu.gbr, Squareboi2-B_Fab.gbr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]
2022-08-23 Update Manual.pdf
    Update manual to reflect V203 firmware, new compile options for POF2JED, removal of RS_N pullup resistor.
2022-09-15 Update README.md
    Add link to video assembly guide
2022-09-15 Update schematic capacitors
    Move capacitor symbols to be closer to devices they're decoupling, fix value typo (10nf to 100nf)
    [Squareboi2.kicad_pcb, Squareboi2.sch]
2022-09-15 Reorganize schematic
    Divide schematic into functional blocks, clean up comments
    [Squareboi2.sch]
2022-09-15 Update capacitor value
    Specify 100n as the decoupling capacitor value
    [RAMboard.kicad_pcb, RAMboard.sch]
2022-09-15 Update capacitor value
    Set decoupling capacitor value to 100n
    [ROMboard.kicad_pcb, ROMboard.sch]
2022-09-15 Update capacitor values
    Set decoupling capacitor values to 100n
    [ROMboard.kicad_pcb, ROMboard.sch]
2022-09-16 Rework schematic
    Clean up and reorganize schematic into functional blocks
    [progshield.sch]
2022-10-09 Create Kicad 5 subfolder
    Move contents of hardware folder into a subfolder, to prepare for eventual update into Kicad 6
    [ATF1502BR-B_Cu.gbr, ATF1502BR-B_Mask.gbr, ATF1502BR-B_SilkS.gbr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]
2022-10-09 Convert mainboard to Kicad 6 format
    [Squareboi2-B_CrtYd.gbr, Squareboi2-B_Cu.gbr, Squareboi2-B_Fab.gbr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]
2022-10-09 Create Conversion Guidelines.txt
    To be used when converting subprojects from KiCad 5 to 6
2022-10-09 Convert RAMBoard to KiCad 6 format
    [RAMboard-B_Cu.gbr, RAMboard-B_Mask.gbr, RAMboard-B_SilkS.gbr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]
2022-10-09 Convert ROMBoard to KiCad 6 format
    [ROMboard-B_Cu.gbr, ROMboard-B_Mask.gbr, ROMboard-B_SilkS.gbr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]
2022-10-09 Convert ROMStackable to KiCad 6
    [ROMboard-B_Cu.gbr, ROMboard-B_Mask.gbr, ROMboard-B_SilkS.gbr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]
2022-10-09 Convert Writeboi to KiCad 6
    [progshield-B_Cu.gbr, progshield-B_Mask.gbr, progshield-B_SilkS.gbr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]
2022-10-09 Convert ROMAdaptor to KiCad 6
    [ROMAdaptor-B_Cu.gbr, ROMAdaptor-B_Mask.gbr, ROMAdaptor-B_SilkS.gbr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]
2022-10-09 Convert ATF Devboard to KiCad 6
    [ATF1502BR-B_Cu.gbr, ATF1502BR-B_Mask.gbr, ATF1502BR-B_SilkS.gbr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]
2022-10-09 Change KiCad 5 folder to legacy
    [ATF1502BR-B_Cu.gbr, ATF1502BR-B_Mask.gbr, ATF1502BR-B_SilkS.gbr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]
2022-10-09 Update Manual.pdf
    Update paths to gerber files, change recommended KiCad version to 6.
2022-10-12 Adjust orientation of RAMboard headers
    Flip the pin headers to the bottom of the board, to better reflect their actual position when assembled.
    [RAMboard.kicad_pcb]
2022-10-12 Adjust orientation of ROMboard headers
    Flip the pin headers to the bottom of the board, to better reflect their actual position when assembled. General cleanup of disconnected traces.
    [ROMboard.kicad_pcb]
2022-10-12 Adjust Orientation of ROMStackable headers
    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
    [ROMboard.kicad_pcb]
2022-10-12 Adjust orientation of ROMAdaptor headers
    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
    [ROMAdaptor.kicad_pcb]
2022-10-12 Clean up Mainboard traces
    Clean up disconnected traces
    [Squareboi2.kicad_pcb]
2022-10-12 Clean up Writeboi traces
    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
    [progshield.kicad_pcb]
2022-10-12 Clean up ATF Devboard traces
    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
    [ATF1502BR.kicad_pcb]
2022-12-03 Set up .gitignore
    Set repository to ignore all the backup folders on KICad 6 projects.
2022-12-04 Add firmware version checking to serial connection
    Make it so pressing the connect button automatically requests the writeboi's build ID, and displays a warning if it's older than the GUI's. Also update logprint function to accept text_color argument.
2022-12-04 Update error log colors
    Update various error log messages to use the new color options on progmanager.logprint()
    [programmercontrol.py]

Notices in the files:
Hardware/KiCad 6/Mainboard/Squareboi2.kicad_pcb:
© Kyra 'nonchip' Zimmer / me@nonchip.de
